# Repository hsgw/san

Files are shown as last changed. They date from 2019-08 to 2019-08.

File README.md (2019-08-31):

SAN 
=======================================

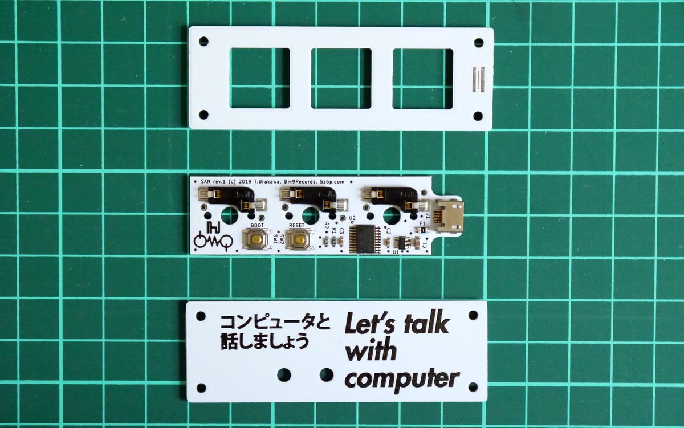
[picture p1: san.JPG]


3keys macro pad.
- STM32F042F6P6
- kailh hotswap socket (MX compatible switch)
- on-chip usb-DFU bootloader
- QMK Firmware(https://github.com/hsgw/qmk_firmware/tree/san)

## Issues
### Rev.1
- 基板上の`BOOT`と`RESET`のシルクが逆になっている
(正しくは`SW1 RESET`, `SW2 BOOT`)

## ビルドガイド
1. 組立てる前にPCと接続してキーボードとして認識されるか、動作を確認する
(ファームウェアが書かれていない場合はブートローダモードで接続されます)
2. ブートローダへ入ってQMK Firmwareからの書き込みを確認する
https://github.com/hsgw/qmk_firmware/san
3. プレート、スイッチを取り付ける
4. ボトムプレートを取り付ける

## ブートローダモード
### 入り方
1. RESETスイッチを押す
2. BOOTスイッチを押す
3. RESETスイッチを離す
4. BOOTスイッチを離す

### (windowsの場合)ドライバを入れ替える
Zadigを使用してOS標準で入るドライバをWinUSBのものに入れ替える必要があります。
1. zadigをダウンロード、解凍する。(https://zadig.akeo.ie/)
2. キーボードをbootloaderモードでPCに接続する   
(この段階では```STM Device in DFU Mode```として認識されているはず)
3. zadigを起動して```Options → List All devices```にチェック
4. ```STM Device in DFU Mode```もしくは```STM32 BOOTLOADER```を選択して、```WinUSB```をインストールする   
**書き換えるデバイス名を必ず確認してから```Replace Driver```を押して下さい。**   
**間違えたデバイスのドライバを書き換えると最悪PCが操作不能になります**

問い合わせ先
Twitter(https://twitter.com/hsgw)もしくはurkwtky[at]gmail.comまで

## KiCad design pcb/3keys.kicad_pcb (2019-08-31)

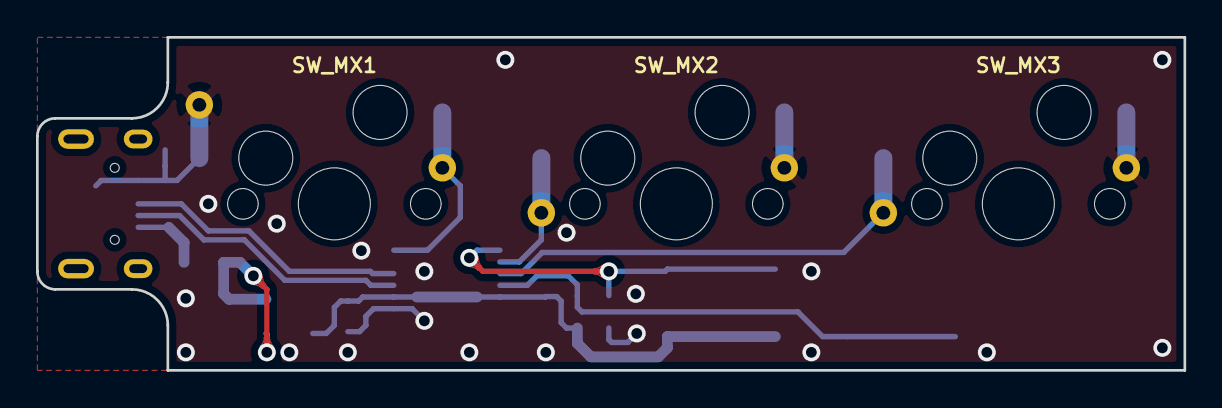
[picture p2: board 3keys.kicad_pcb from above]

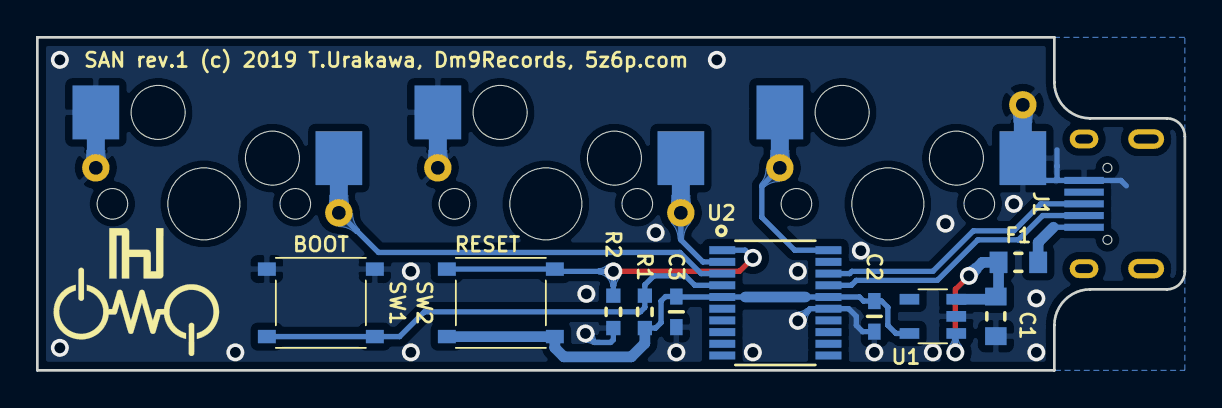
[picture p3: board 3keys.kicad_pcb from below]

Board: 2 copper layers, 63.8 x 18.5 mm, 14 parts (11 on the bottom side), 11 nets.

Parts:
C1: 10u; C2012_hand
C2, C3: 0.1u; C1608_Hand
F1: 100mA; C2012_hand
J1: USB_OTG; USB-microB-LCSC-U-F-M5DD-W-2
R1, R2: 10k; R1608_Hand
SW1, SW2: SW_Push; TACT_5.1x5.1
SW_MX1, SW_MX2, SW_MX3: SW_Push; SW_kailh_MX_socket_repairable_small
U1: TLV70012_SOT23-5; SOT-23-5
U2: STM32F042F6Px; TSSOP-20_4.4x6.5mm_Pitch0.65mm

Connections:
+3V3: C2.1, C3.1, R1.1, SW2.1, U1.5, U2.5, U2.16
/SW1: SW_MX1.2, U2.20
/SW2: SW_MX2.1, U2.2
/SW3: SW_MX3.1, U2.3
/USB_D+: J1.3, U2.18
/USB_D-: J1.2, U2.17
GND: C1.2, C2.2, C3.2, J1.5, R2.2, SW1.1, SW_MX1.1, SW_MX2.2, SW_MX3.2, U1.2, U2.15
unnamed: C1.1, F1.1, U1.1, U1.3
unnamed: R1.2, SW1.2, U2.4
unnamed: R2.1, SW2.2, U2.1
VBUS: F1.2, J1.1

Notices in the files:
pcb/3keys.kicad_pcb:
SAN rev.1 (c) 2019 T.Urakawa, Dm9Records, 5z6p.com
